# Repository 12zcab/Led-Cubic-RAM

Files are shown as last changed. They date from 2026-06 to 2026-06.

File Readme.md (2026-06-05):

# A SOUP-A COOL RAM-based LED CUBE for Retro Computers!
## Images
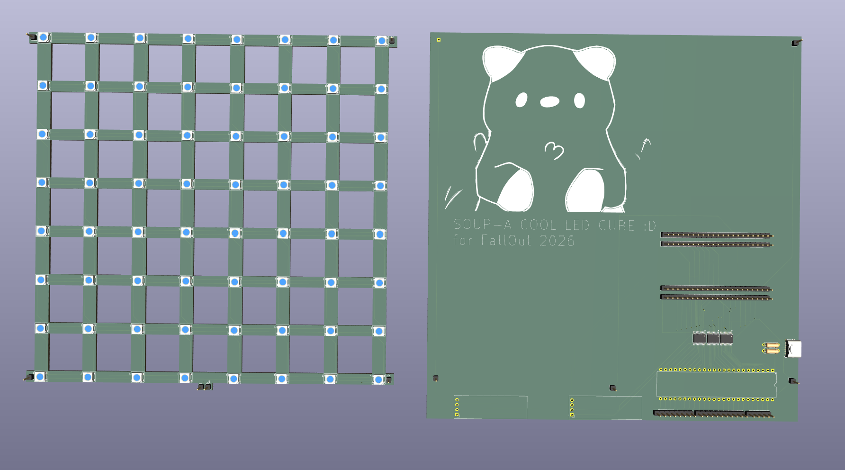
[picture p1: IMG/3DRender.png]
3DRender

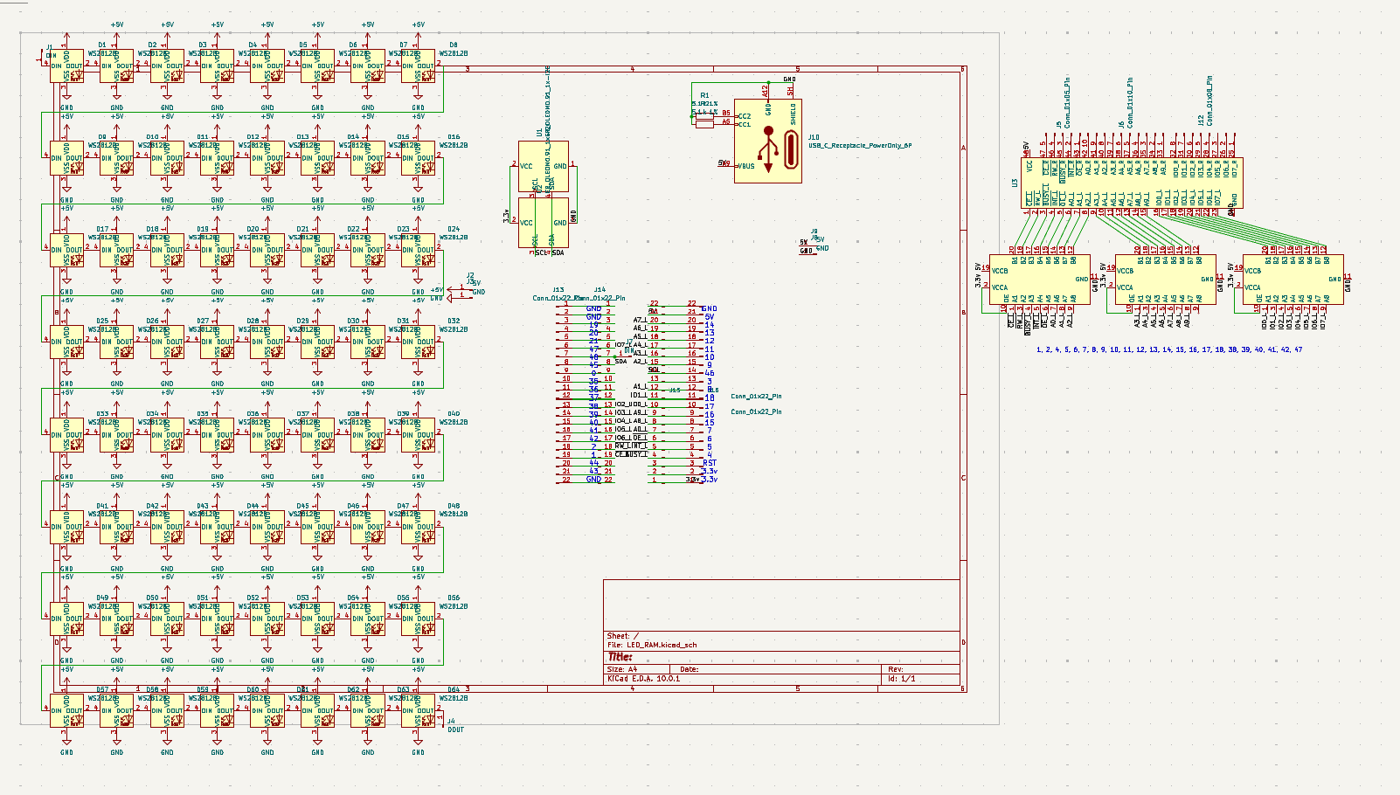
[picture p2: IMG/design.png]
Design

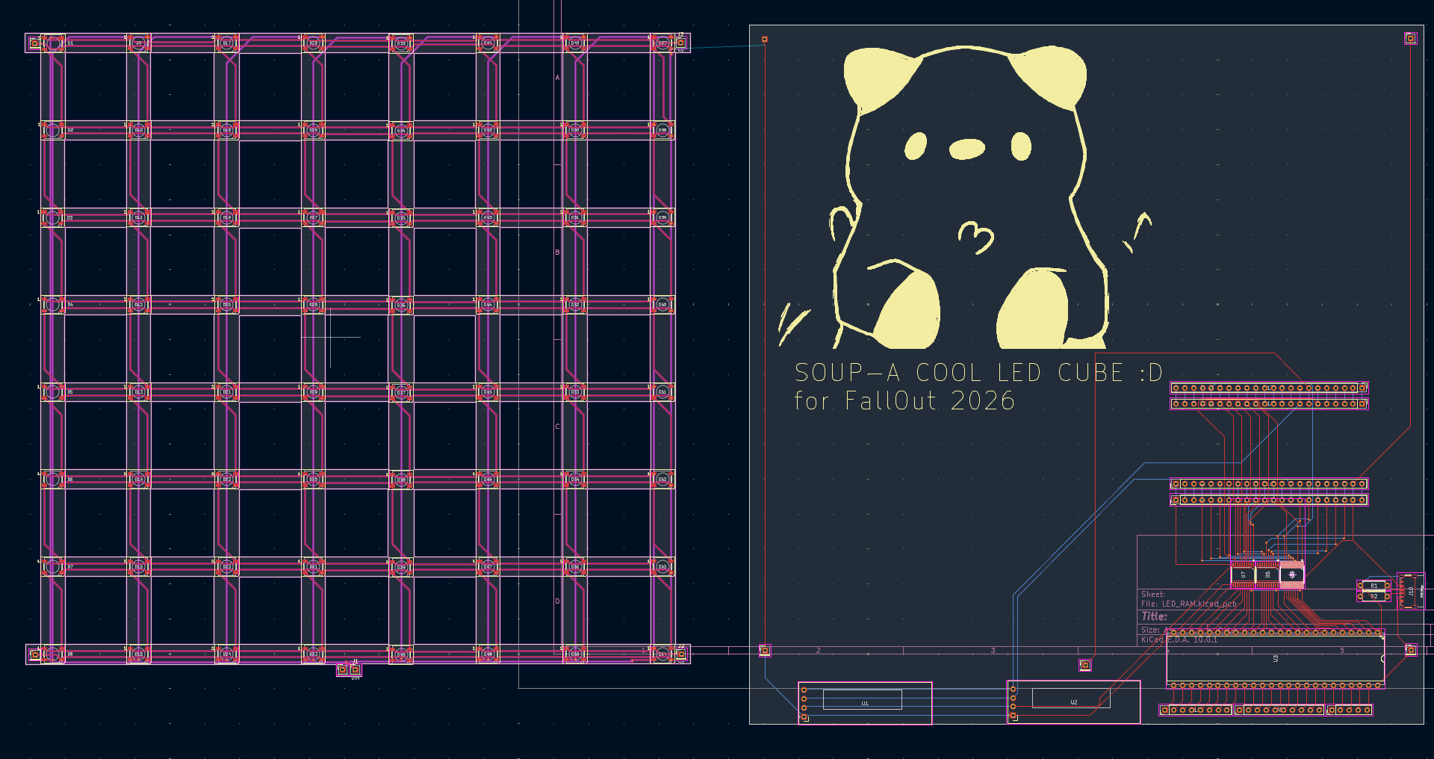
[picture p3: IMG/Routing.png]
Routing

## Zine Page
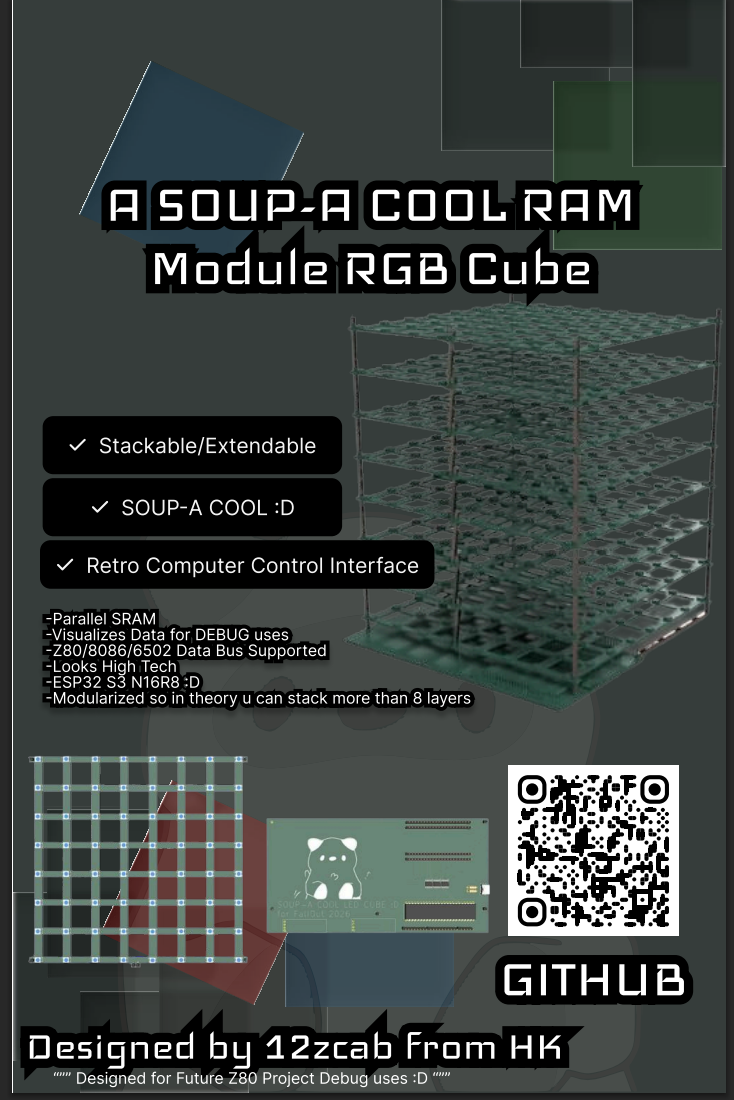
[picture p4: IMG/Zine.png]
Zine

## What it does?
It have a normal SRAM pinout for Retro Computer. HOWEVER,ANY DATA YOU STORED INTO IT WILL BE RESULTED AS LIGHT SHINING!!!!
Each RGB LED = 1 Byte from 0 to FF , meaning it have 16 Color Depth for each channel (RGB)
It's works similar to a VRAM with a parallel Dual-DataBus CMOS SRAM.
Really Cool for retro computers as a Screen or a Output or even for Debugging
## Why I made this?
Because I have designed and will design many Z80 and 8086,88 based retro computers and VGA is just too hard for me to design but I don't really like using a Arduino or Serial IC to Debug so I made this RGB Led Cube with 512 Leds to Visualize my RAM usage :D
## How to Assemble it?
As I have not yet built it irl,I can't provide and photo right now...
But Basically it work like this:
1.You need to Order a PCBA service from JLCPCB as this save u a lot of time and much safer as soldering SMT components is not something everybody can handle.

2.You need to Solder IC sockets and PinHeaders

3.Prepare a Hard Copper 0.8mm Diameter Wire and split it into 5 segments each about 30CM

4.solder the copper Wire into the 5V and GND hole on the mainboard PCB

5.Put in esp32 and the RAM and the Oled to test if the mainboard works

6.Start stacking the RGB Led Board and solder the GND and 5V hole of it,remember to align all the DIN DOUT hole on the same side.

7.solder the DIN hole of the bottom RGB LED Board to the Main Board.

8.Solder the Upper DIN hole to the Lower DOUT hole for every single RGB LED Board (YEAH THIS PROJECT IS EXTENDABLE U BASICALLY CAN STACK UNLIMITED RGB BOARDS!!(Yah but the FPS will be lowered actually))

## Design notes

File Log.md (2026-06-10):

Day 1 25/5/2026

What I did today:
1.Decided the Function

&#x20;  - First Func: as a Ram for z80 that can be visualized

&#x20;  - Sec Func: as a LED Cube

2.Decided the components

&#x20;     - https://jlcpcb.com/partdetail/XINGLIGHT-XL\_5050RGBC2812B/C2843785

&#x20;  - MPU6050

&#x20;  - 12864 I2C Screen

&#x20;  - ESP32 S3 Development Board

&#x20;  - CY7C130 (Kicad)

3.Made the Symbol and footprint of the CY7C130

4.decided to have a 3.3v to 5v IO IC between ESP32 and the RAM (74LVC245)

What I need to do next time:
1.Route the PCB

2.Finish the RAM circuit

3.Add a Port for Z80

4.Prepare a BOM

5.Research on how to use the service of JLCPCB Assembly

6.Write a Simple Program for Firmware

7.Write Readme.md File

8.Design a Case for It

Day 2 27/5/2026

What I did today:

1.Finished the simple wiring thing :D

2.Finished the Z80 port and Esp32 with 3.3v to 5v signal ic

3.Finished the Routing of the LED cube pcb layers

What i need to next time

1.Route the PCB

2.design a Zine Page for it

3.Prepare a BOM

4.Write a Simple Program for Firmware

5.Write Readme.md File

https://jlcpcb.com/partdetail/XINGLIGHT-XL\_5050RGBC2812B/C2843785

Day3 & Day4 Part1 Part2:
1.Routed the PCB
2.Prepared the BOM
btw i will use PCBA service for the SMT parts(RGB LED and the 74 LogicIC).
3.Prepared the Component Placement File and Gerber File for JLCPCB :D

Day 4 5/6/2026

What I need to do:
1.Write a Simple Test Program
2.Zine Page design

Done both. :D
Submitting for 1st Review :D

Day 5 10/6/2026
Adding more detail to the Zine for Resubmision
Added Total Cost calculation and estimate for BOM.csv
Resubmitting for review

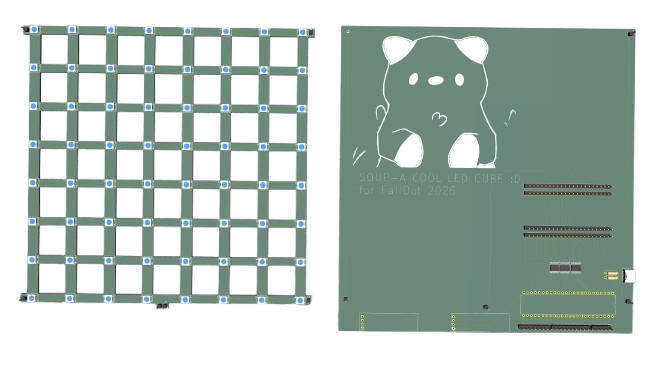
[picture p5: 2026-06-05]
IMG/3DRender-removebg-preview.png

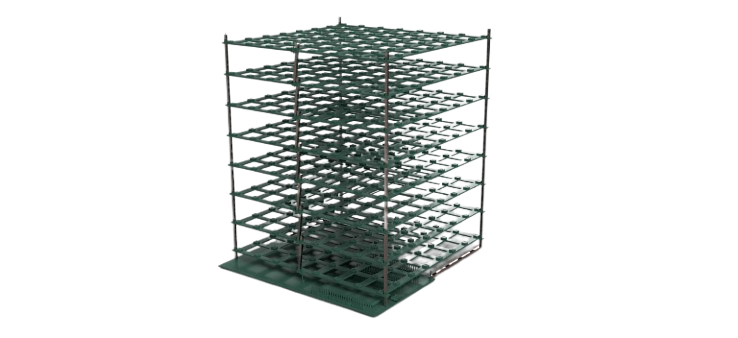
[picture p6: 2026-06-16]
IMG/LEDRGBCUBE-removebg-preview.png

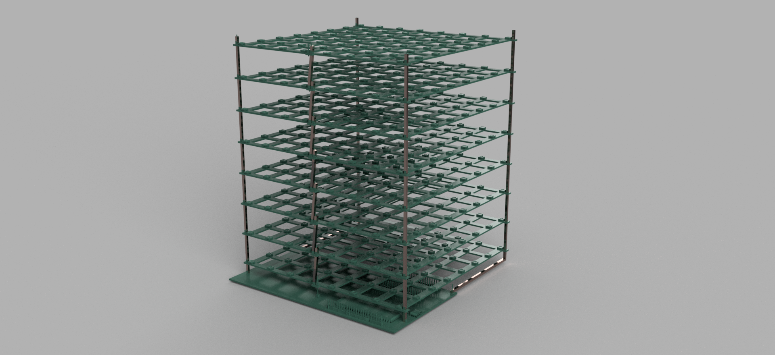
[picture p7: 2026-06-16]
LED_RAM/LEDRGBCUBE.png

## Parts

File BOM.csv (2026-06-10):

Component Type(Basic Usage) | Component Specific Name | Component Quantity | Link | Quantity Price RMB | Price RMB | Price USD
RGB LED | WS2812B | 64 | https://jlcpcb.com/partdetail/XINGLIGHT-XL\_5050RGBC2812B/C2843785 | Not Suitable | Not Suitable | 19.2
USB-C Connector (Power Only) | USB_C_Receptacle_PowerOnly_6P | 1 | https://jlcpcb.com/partdetail/SHOUHAN-TYPE_C6P/C456012 | Not Suitable | Not Suitable | 0.04
Resistor | 5.1k 1% | 2 | https://world.taobao.com/item/dW1IZW1NbW1WWGJEODhjN3FEejFjdz09.htm | Not Suitable | 1.76 | 0.264
OLED Display | 12832 I2C OLED | 1 | https://world.taobao.com/item/T3FLN1ZNbHcxWjhnUk1UVUxYU0Q3QT09.htm | 8.12 | 8.12 | 1.218
Dual-Port SRAM | CY7C130 | 1 | https://world.taobao.com/item/586275659639.htmw | 9.1 | 9.1 | 1.365
Voltage-Level Translator IC | TXS0108EPW | 3 | https://jlcpcb.com/partdetail/TexasInstruments-TXS0108EPWR/C17206 | Not Suitable | Not Suitable | 1.08
Total |  |  |  |  |  | 23.167
Total with PCB and Shipping Estimate Cost |  |  |  |  |  | 38

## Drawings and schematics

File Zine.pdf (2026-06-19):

# A SOUP-A COOL RAM

# Module RGB Cube

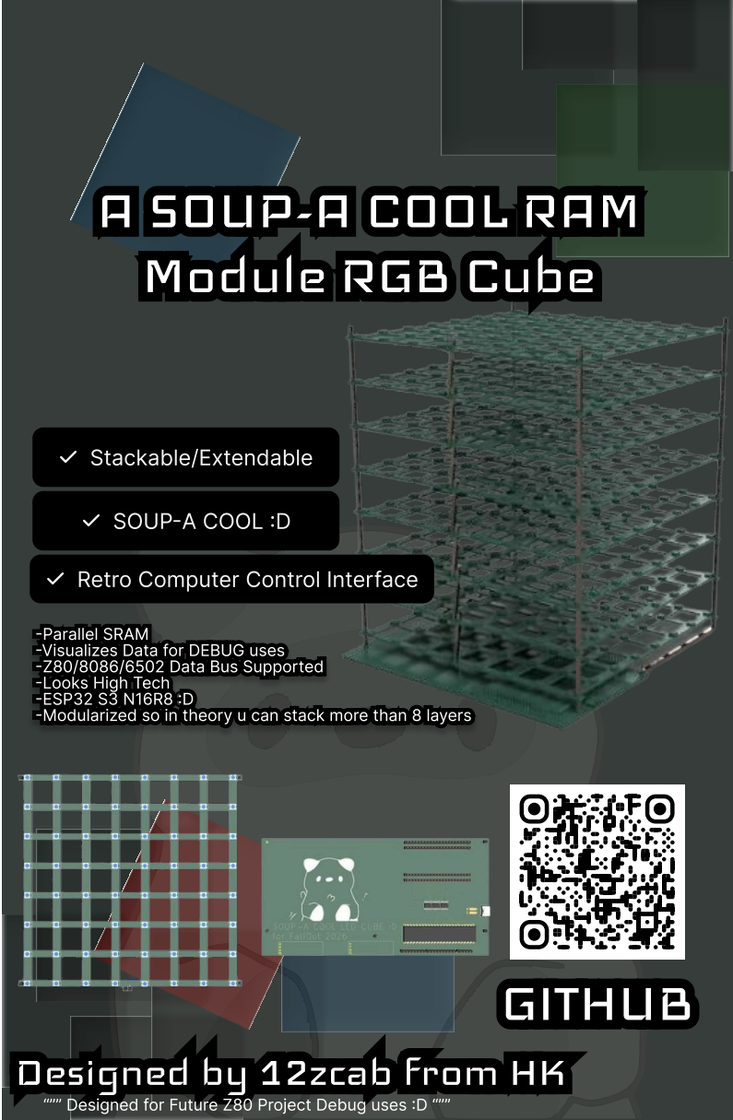
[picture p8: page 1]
Stackable/Extendable; SOUP-A COOL :D; GITHUB

Retro Computer Control Interface

-Parallel SRAM
-Visualizes Data for DEBUG uses
-Z80/8086/6502 Data Bus Supported
-Looks High Tech
-ESP32 S3 N16R8 :D
-Modularized so in theory u can stack more than 8 layers

Designed by 12zcab from HK “”” Designed for Future Z80 Project Debug uses :D “””

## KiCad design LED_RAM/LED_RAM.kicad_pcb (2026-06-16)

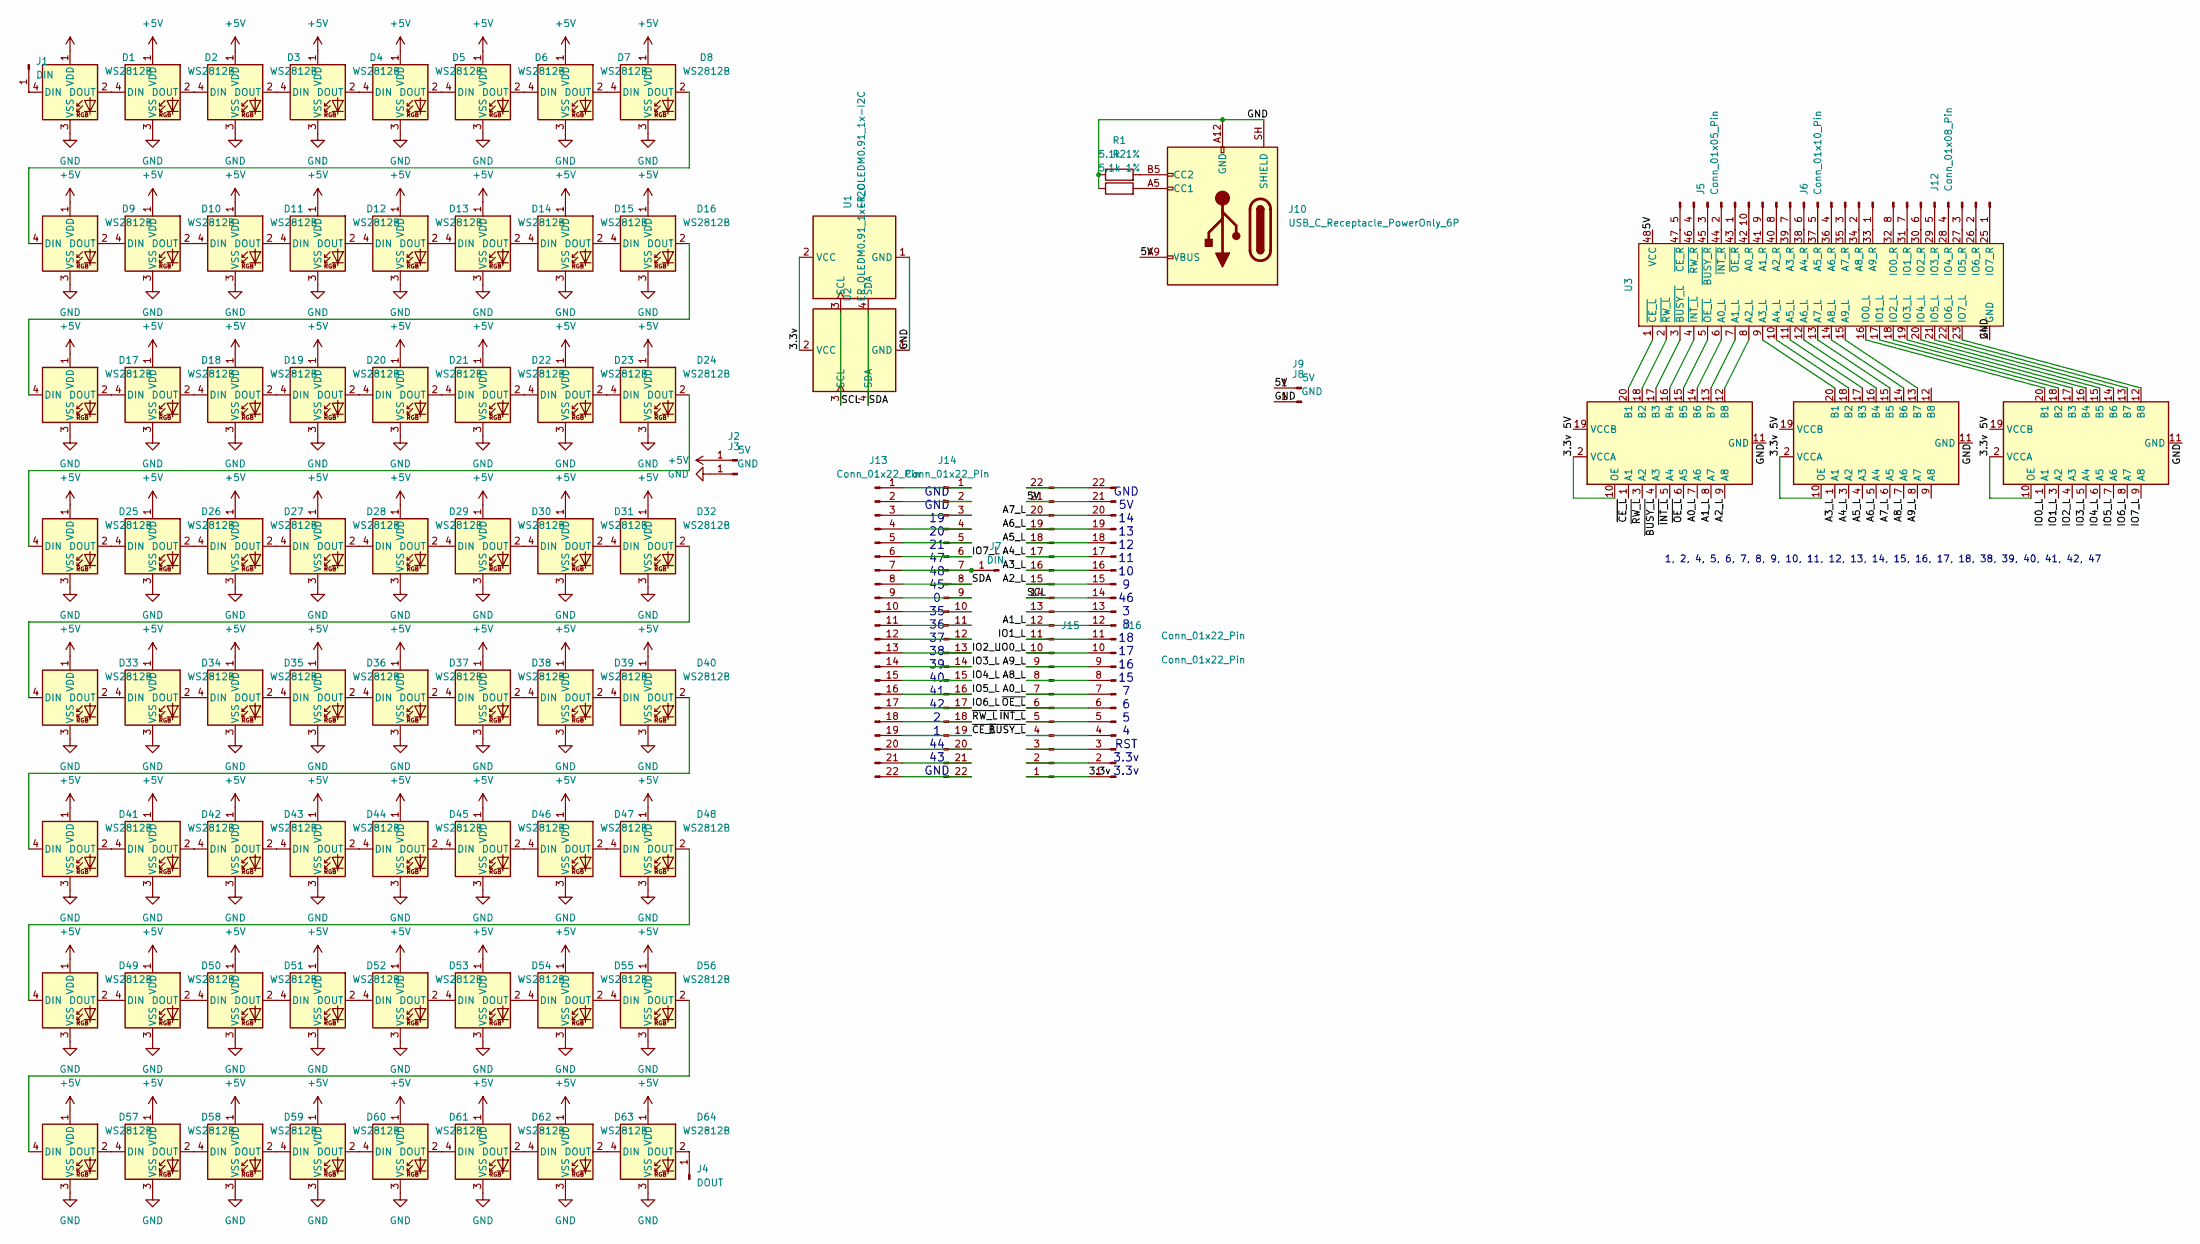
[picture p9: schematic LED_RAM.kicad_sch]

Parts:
D1, D2, D3, D4, D5, D6, D7, D8, D9, D10, D11, D12, D13, D14, D15, D16, D17, D18, D19, D20, D21, D22, D23, D24, D25, D26, D27, D28, D29, D30, D31, D32, D33, D34, D35, D36, D37, D38, D39, D40, D41, D42, D43, D44, D45, D46, D47, D48, D49, D50, D51, D52, D53, D54, D55, D56, D57, D58, D59, D60, D61, D62, D63, D64: WS2812B; LED_WS2812B_PLCC4_5.0x5.0mm_P3.2mm
J1, J7: DIN; PinHeader_1x01_P2.54mm_Vertical
J2, J9: 5V; PinHeader_1x01_P2.54mm_Vertical
J3, J8: GND; PinHeader_1x01_P2.54mm_Vertical
J4: DOUT; PinHeader_1x01_P2.54mm_Vertical
J5: Conn_01x05_Pin; PinHeader_1x05_P2.54mm_Vertical
J6: Conn_01x10_Pin; PinHeader_1x10_P2.54mm_Vertical
J10: USB_C_Receptacle_PowerOnly_6P; USB_C_Receptacle_GCT_USB4125-xx-x_6P_TopMnt_Horizontal
J12: Conn_01x08_Pin; PinHeader_1x08_P2.54mm_Vertical
J13, J14, J15, J16: Conn_01x22_Pin; PinHeader_1x22_P2.54mm_Vertical
R1, R2: 5.1k 1%; R_Axial_DIN0207_L6.3mm_D2.5mm_P7.62mm_Horizontal
U1, U2: ER_OLEDM0.91_1x-I2C
U3: DIP-48_W15.24mm
U5, U6, U7: TXS0108EPW; TSSOP-20_4.4x6.5mm_P0.65mm

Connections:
+5V: D1.1 (VDD), D2.1 (VDD), D3.1 (VDD), D4.1 (VDD), D5.1 (VDD), D6.1 (VDD), D7.1 (VDD), D8.1 (VDD), D9.1 (VDD), D10.1 (VDD), D11.1 (VDD), D12.1 (VDD), D13.1 (VDD), D14.1 (VDD), D15.1 (VDD), D16.1 (VDD), D17.1 (VDD), D18.1 (VDD), D19.1 (VDD), D20.1 (VDD), D21.1 (VDD), D22.1 (VDD), D23.1 (VDD), D24.1 (VDD), D25.1 (VDD), D26.1 (VDD), D27.1 (VDD), D28.1 (VDD), D29.1 (VDD), D30.1 (VDD), D31.1 (VDD), D32.1 (VDD), D33.1 (VDD), D34.1 (VDD), D35.1 (VDD), D36.1 (VDD), D37.1 (VDD), D38.1 (VDD), D39.1 (VDD), D40.1 (VDD), D41.1 (VDD), D42.1 (VDD), D43.1 (VDD), D44.1 (VDD), D45.1 (VDD), D46.1 (VDD), D47.1 (VDD), D48.1 (VDD), D49.1 (VDD), D50.1 (VDD), D51.1 (VDD), D52.1 (VDD), D53.1 (VDD), D54.1 (VDD), D55.1 (VDD), D56.1 (VDD), D57.1 (VDD), D58.1 (VDD), D59.1 (VDD), D60.1 (VDD), D61.1 (VDD), D62.1 (VDD), D63.1 (VDD), D64.1 (VDD), J2.1 (Pin_1_1); also elsewhere on the board
/3.3v: J15.1, J16.1, U1.2 (VCC), U2.2 (VCC), U5.2 (VCCA), U5.10 (OE), U6.2 (VCCA), U6.10 (OE), U7.2 (VCCA), U7.10 (OE)
/5V: J9.1 (Pin_1_1), J10.A9 (VBUS), J10.B9 (VBUS), J15.21, J16.21, U3.48 (VCC), U5.19 (VCCB), U6.19 (VCCB), U7.19 (VCCB); also elsewhere on the board
/A0_L: J15.7, J16.7, U5.7 (A6)
/A1_L: J15.12, J16.12, U5.8 (A7)
/A2_L: J15.15, J16.15, U5.9 (A8)
/A3_L: J15.16, J16.16, U6.1 (A1)
/A4_L: J15.17, J16.17, U6.3 (A2)
/A5_L: J15.18, J16.18, U6.4 (A3)
/A6_L: J15.19, J16.19, U6.5 (A4)
/A7_L: J15.20, J16.20, U6.6 (A5)
/A8_L: J15.8, J16.8, U6.7 (A6)
/A9_L: J15.9, J16.9, U6.8 (A7)
/IO0_L: J15.10, J16.10, U7.1 (A1)
/IO1_L: J15.11, J16.11, U7.3 (A2)
/IO2_L: J13.13, J14.13, U7.4 (A3)
/IO3_L: J13.14, J14.14, U7.5 (A4)
/IO4_L: J13.15, J14.15, U7.6 (A5)
/IO5_L: J13.16, J14.16, U7.7 (A6)
/IO6_L: J13.17, J14.17, U7.8 (A7)
/IO7_L: J13.6, J14.6, U7.9 (A8)
/SCL: J15.14, J16.14, U1.3 (SCL), U2.3 (SCL)
/SDA: J13.8, J14.8, U1.4 (SDA), U2.4 (SDA)
/~BUSY_L: J15.4, J16.4, U5.4 (A3)
/~CE_L: J13.19, J14.19, U5.1 (A1)
/~INT_L: J15.5, J16.5, U5.5 (A4)
/~OE_L: J15.6, J16.6, U5.6 (A5)
/~RW_L: J13.18, J14.18, U5.3 (A2)
GND: D1.3 (VSS), D2.3 (VSS), D3.3 (VSS), D4.3 (VSS), D5.3 (VSS), D6.3 (VSS), D7.3 (VSS), D8.3 (VSS), D9.3 (VSS), D10.3 (VSS), D11.3 (VSS), D12.3 (VSS), D13.3 (VSS), D14.3 (VSS), D15.3 (VSS), D16.3 (VSS), D17.3 (VSS), D18.3 (VSS), D19.3 (VSS), D20.3 (VSS), D21.3 (VSS), D22.3 (VSS), D23.3 (VSS), D24.3 (VSS), D25.3 (VSS), D26.3 (VSS), D27.3 (VSS), D28.3 (VSS), D29.3 (VSS), D30.3 (VSS), D31.3 (VSS), D32.3 (VSS), D33.3 (VSS), D34.3 (VSS), D35.3 (VSS), D36.3 (VSS), D37.3 (VSS), D38.3 (VSS), D39.3 (VSS), D40.3 (VSS), D41.3 (VSS), D42.3 (VSS), D43.3 (VSS), D44.3 (VSS), D45.3 (VSS), D46.3 (VSS), D47.3 (VSS), D48.3 (VSS), D49.3 (VSS), D50.3 (VSS), D51.3 (VSS), D52.3 (VSS), D53.3 (VSS), D54.3 (VSS), D55.3 (VSS), D56.3 (VSS), D57.3 (VSS), D58.3 (VSS), D59.3 (VSS), D60.3 (VSS), D61.3 (VSS), D62.3 (VSS), D63.3 (VSS), D64.3 (VSS), J3.1 (Pin_1_1), J8.1 (Pin_1_1), J10.A12 (GND), J10.B12 (GND), J10.SH (SHIELD), R1.1, R2.1, U1.1 (GND), U2.1 (GND), U3.24 (GND), U5.11 (GND), U6.11 (GND), U7.11 (GND); also elsewhere on the board
unnamed: D1.4 (DIN), J1.1 (Pin_1_1)
unnamed: D1.2 (DOUT), D2.4 (DIN)
unnamed: D2.2 (DOUT), D3.4 (DIN)
unnamed: D3.2 (DOUT), D4.4 (DIN)
unnamed: D4.2 (DOUT), D5.4 (DIN)
unnamed: D5.2 (DOUT), D6.4 (DIN)
unnamed: D6.2 (DOUT), D7.4 (DIN)
unnamed: D7.2 (DOUT), D8.4 (DIN)
unnamed: D8.2 (DOUT), D9.4 (DIN)
unnamed: D9.2 (DOUT), D10.4 (DIN)
unnamed: D10.2 (DOUT), D11.4 (DIN)
unnamed: D11.2 (DOUT), D12.4 (DIN)
unnamed: D12.2 (DOUT), D13.4 (DIN)
unnamed: D13.2 (DOUT), D14.4 (DIN)
unnamed: D14.2 (DOUT), D15.4 (DIN)
unnamed: D15.2 (DOUT), D16.4 (DIN)
unnamed: D16.2 (DOUT), D17.4 (DIN)
unnamed: D17.2 (DOUT), D18.4 (DIN)
unnamed: D18.2 (DOUT), D19.4 (DIN)
unnamed: D19.2 (DOUT), D20.4 (DIN)
unnamed: D20.2 (DOUT), D21.4 (DIN)
unnamed: D21.2 (DOUT), D22.4 (DIN)
unnamed: D22.2 (DOUT), D23.4 (DIN)
unnamed: D23.2 (DOUT), D24.4 (DIN)
unnamed: D24.2 (DOUT), D25.4 (DIN)
unnamed: D25.2 (DOUT), D26.4 (DIN)
unnamed: D26.2 (DOUT), D27.4 (DIN)
unnamed: D27.2 (DOUT), D28.4 (DIN)
unnamed: D28.2 (DOUT), D29.4 (DIN)
unnamed: D29.2 (DOUT), D30.4 (DIN)
unnamed: D30.2 (DOUT), D31.4 (DIN)
unnamed: D31.2 (DOUT), D32.4 (DIN)
unnamed: D32.2 (DOUT), D33.4 (DIN)
unnamed: D33.2 (DOUT), D34.4 (DIN)
unnamed: D34.2 (DOUT), D35.4 (DIN)
unnamed: D35.2 (DOUT), D36.4 (DIN)
unnamed: D36.2 (DOUT), D37.4 (DIN)
unnamed: D37.2 (DOUT), D38.4 (DIN)
unnamed: D38.2 (DOUT), D39.4 (DIN)
unnamed: D39.2 (DOUT), D40.4 (DIN)
unnamed: D40.2 (DOUT), D41.4 (DIN)
unnamed: D41.2 (DOUT), D42.4 (DIN)
unnamed: D42.2 (DOUT), D43.4 (DIN)
unnamed: D43.2 (DOUT), D44.4 (DIN)
unnamed: D44.2 (DOUT), D45.4 (DIN)
unnamed: D45.2 (DOUT), D46.4 (DIN)
unnamed: D46.2 (DOUT), D47.4 (DIN)
unnamed: D47.2 (DOUT), D48.4 (DIN)
unnamed: D48.2 (DOUT), D49.4 (DIN)
unnamed: D49.2 (DOUT), D50.4 (DIN)
unnamed: D50.2 (DOUT), D51.4 (DIN)
unnamed: D51.2 (DOUT), D52.4 (DIN)
unnamed: D52.2 (DOUT), D53.4 (DIN)
unnamed: D53.2 (DOUT), D54.4 (DIN)
unnamed: D54.2 (DOUT), D55.4 (DIN)
unnamed: D55.2 (DOUT), D56.4 (DIN)
unnamed: D56.2 (DOUT), D57.4 (DIN)
unnamed: D57.2 (DOUT), D58.4 (DIN)
unnamed: D58.2 (DOUT), D59.4 (DIN)
unnamed: D59.2 (DOUT), D60.4 (DIN)
unnamed: D60.2 (DOUT), D61.4 (DIN)
unnamed: D61.2 (DOUT), D62.4 (DIN)
unnamed: D62.2 (DOUT), D63.4 (DIN)
unnamed: D63.2 (DOUT), D64.4 (DIN)
unnamed: D64.2 (DOUT), J4.1 (Pin_1_1)
unnamed: J5.1, U3.43 (~OE_R)
unnamed: J5.2, U3.44 (~INT_R)
unnamed: J5.3, U3.45 (~BUSY_R)
unnamed: J5.4, U3.46 (~RW_R)
unnamed: J5.5, U3.47 (~CE_R)
unnamed: J6.1, U3.33 (A9_R)
unnamed: J6.2, U3.34 (A8_R)
unnamed: J6.3, U3.35 (A7_R)
unnamed: J6.4, U3.36 (A6_R)
unnamed: J6.5, U3.37 (A5_R)
unnamed: J6.6, U3.38 (A4_R)
unnamed: J6.7, U3.39 (A3_R)
unnamed: J6.8, U3.40 (A2_R)
unnamed: J6.9, U3.41 (A1_R)
unnamed: J6.10, U3.42 (A0_R)
unnamed: J10.A5 (CC1), R2.2
unnamed: J10.B5 (CC2), R1.2
unnamed: J12.1, U3.25 (IO7_R)
unnamed: J12.2, U3.26 (IO6_R)
unnamed: J12.3, U3.27 (IO5_R)
unnamed: J12.4, U3.28 (IO4_R)
unnamed: J12.5, U3.29 (IO3_R)
unnamed: J12.6, U3.30 (IO2_R)
unnamed: J12.7, U3.31 (IO1_R)
unnamed: J12.8, U3.32 (IO0_R)
unnamed: J13.1, J14.1
unnamed: J13.2, J14.2
unnamed: J13.3, J14.3
unnamed: J13.4, J14.4
unnamed: J13.5, J14.5
unnamed: J7.1 (Pin_1_1), J13.7, J14.7
unnamed: J13.9, J14.9
unnamed: J13.10, J14.10
unnamed: J13.11, J14.11
unnamed: J13.12, J14.12
unnamed: J13.20, J14.20
unnamed: J13.21, J14.21
unnamed: J13.22, J14.22
unnamed: J15.2, J16.2
unnamed: J15.3, J16.3
unnamed: J15.13, J16.13
unnamed: J15.22, J16.22
unnamed: U3.6 (A0_L), U5.14 (B6)
unnamed: U3.7 (A1_L), U5.13 (B7)
unnamed: U3.8 (A2_L), U5.12 (B8)
unnamed: U3.9 (A3_L), U6.20 (B1)
unnamed: U3.10 (A4_L), U6.18 (B2)
unnamed: U3.11 (A5_L), U6.17 (B3)
unnamed: U3.12 (A6_L), U6.16 (B4)
unnamed: U3.13 (A7_L), U6.15 (B5)
unnamed: U3.14 (A8_L), U6.14 (B6)
unnamed: U3.15 (A9_L), U6.13 (B7)
unnamed: U3.16 (IO0_L), U7.20 (B1)
unnamed: U3.17 (IO1_L), U7.18 (B2)
unnamed: U3.18 (IO2_L), U7.17 (B3)
unnamed: U3.19 (IO3_L), U7.16 (B4)
unnamed: U3.20 (IO4_L), U7.15 (B5)
unnamed: U3.21 (IO5_L), U7.14 (B6)
unnamed: U3.22 (IO6_L), U7.13 (B7)
unnamed: U3.23 (IO7_L), U7.12 (B8)
unnamed: U3.3 (~BUSY_L), U5.17 (B3)
unnamed: U3.1 (~CE_L), U5.20 (B1)
unnamed: U3.4 (~INT_L), U5.16 (B4)
unnamed: U3.5 (~OE_L), U5.15 (B5)
unnamed: U3.2 (~RW_L), U5.18 (B2)

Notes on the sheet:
GND GND 19 20 21 47 48 45 0 35 36 37 38 39 40 41 42 2 1 44 43 GND
1, 2, 4, 5, 6, 7, 8, 9, 10, 11, 12, 13, 14, 15, 16, 17, 18, 38, 39, 40, 41, 42, 47
GND 5V 14 13 12 11 10 9 46 3 8 18 17 16 15 7 6 5 4 RST 3.3v 3.3v

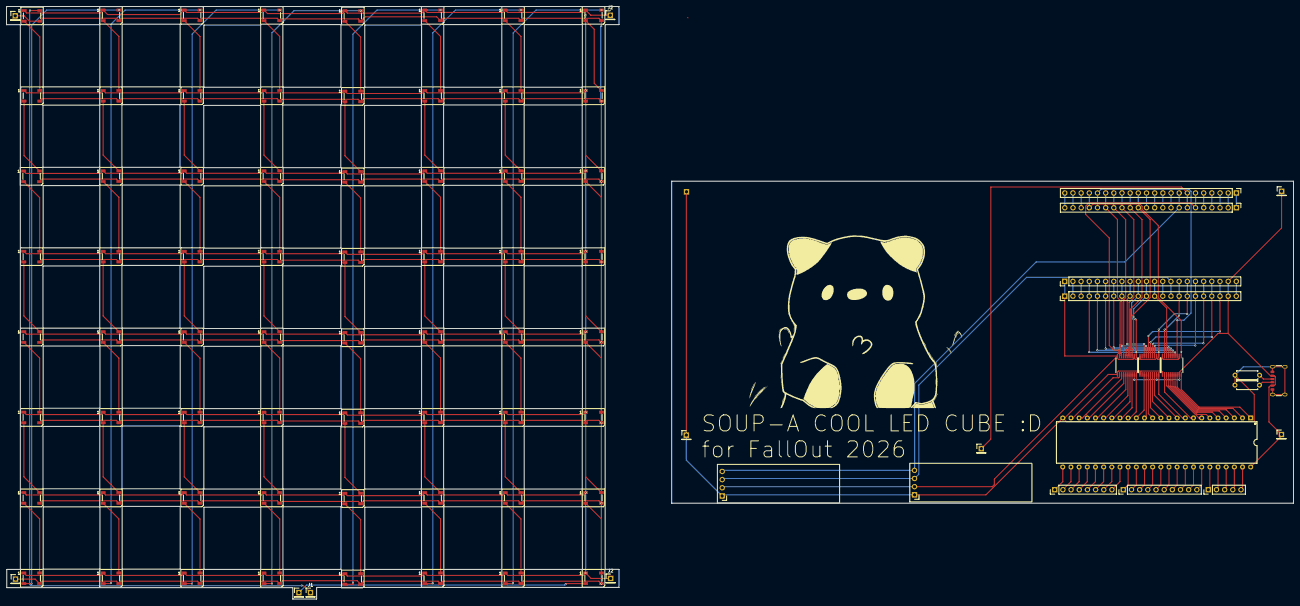
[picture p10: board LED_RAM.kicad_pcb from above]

Board: 2 copper layers, 400.1 x 184.2 mm, 90 parts (0 on the bottom side), 159 nets.

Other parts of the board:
J2#2, J9#2: 5V; PinHeader_1x01_P2.54mm_Vertical
J3#2: GND; PinHeader_1x01_P2.54mm_Vertical

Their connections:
+5V: J2#2.1 (Pin_1_1); also elsewhere on the board
/5V: J9#2.1 (Pin_1_1); also elsewhere on the board
GND: J3#2.1 (Pin_1_1); also elsewhere on the board

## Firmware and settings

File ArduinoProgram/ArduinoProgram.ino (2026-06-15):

#include <FastLED.h>
#define NUM_LEDS 512
#define OE_Pin 6
#define CE_Pin 1
#define WR_Pin 2
const byte AddressPins[10] = { 7,8,9,10,11,12,13,14,15,16 }; //lsb to msb
const byte DataPins[8] = { 17,18,38,39,41,42,43,47 } //lsb to msb
CRGB leds[NUM_LEDS];
uint8_t hue = 0;

void setup() { 
  FastLED.addLeds<WS2812, 48>(leds, NUM_LEDS); 
  pinMode(OE_Pin, OUTPUT);
  pinMode(CE_Pin, OUTPUT);
  pinMode(WR_Pin, OUTPUT);
  digitalWrite(OE_Pin,1);
  digitalWrite(CE_Pin,1);
  digitalWrite(WR_Pin,1);
  for (uint8_t count = 0, count < 10 ; count++){
    pinMode(AddressPins[count], OUTPUT);
  }
  for (uint8_t count = 0, count < 8 ; count++){
    pinMode(DataPins[count], INPUT)
  }
}
uint8_t readMem(uint16_t Addr){
  for (uint8_t n = 0; n < 10 ; n++){
    digitalWrite(AddressPins[n],(Addr >> n) & 0x01);
  }
  uint8_t data = 0;
  digitalWrite(OE_Pin,0);
  digitalWrite(CE_Pin,0);
  for (int i = 0; i < 8; i++) {
    if (digitalRead(DataPins[i]) == HIGH) {
      data |= (1 << i);
  }
  digitalWrite(OE_Pin,1);
  digitalWrite(CE_Pin,1);
}
void readMemIntoRGB(){
  for (uint16_t Addr = 0; Addr < 512 ; Addr++){
    data = readMem(Addr);
    leds[Addr] = CHSV(data,255,255);
  }
}
void loop() {
  readMemIntoRGB()
}
